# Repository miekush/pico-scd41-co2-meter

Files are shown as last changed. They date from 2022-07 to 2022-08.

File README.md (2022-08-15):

# Raspberry Pi Pico CO2 Meter

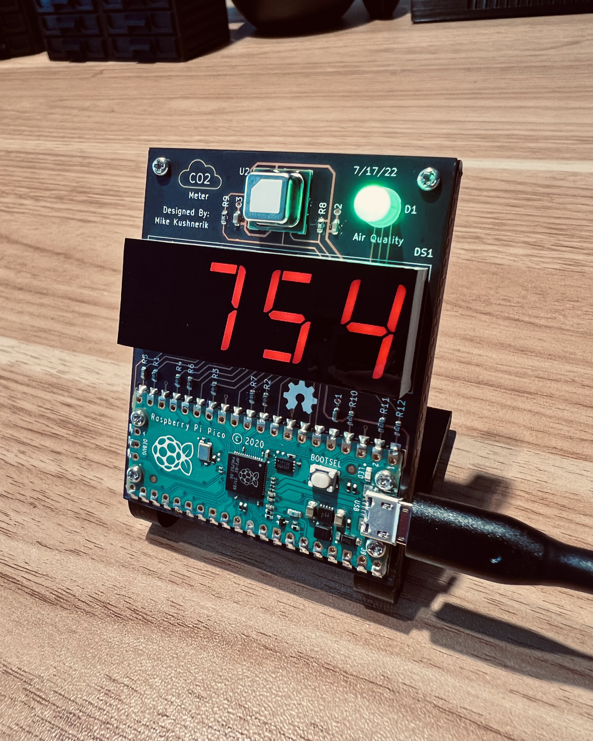
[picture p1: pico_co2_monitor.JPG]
Assembled Unit


# PCB
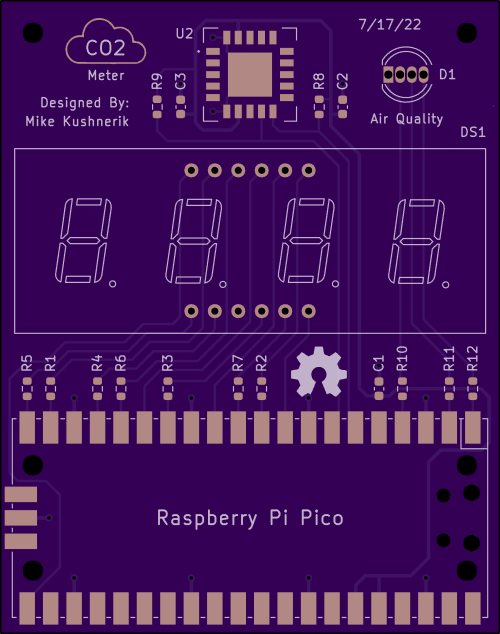
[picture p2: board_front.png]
Board Image


Designed by Mike Kushnerik (miekush) in KiCad V6

# License

MKE supports the open source hardware community by sharing hardware design files freely on GitHub!

Please support MKE by purchasing products on [Tindie](https://www.tindie.com/stores/mkengineering/)!

Designed by Mike Kushnerik (miekush)

Licensed under [Creative Commons Attribution-ShareAlike CC BY-SA 4.0](http://creativecommons.org/licenses/by-sa/4.0/)

All text above must be included in any redistribution!

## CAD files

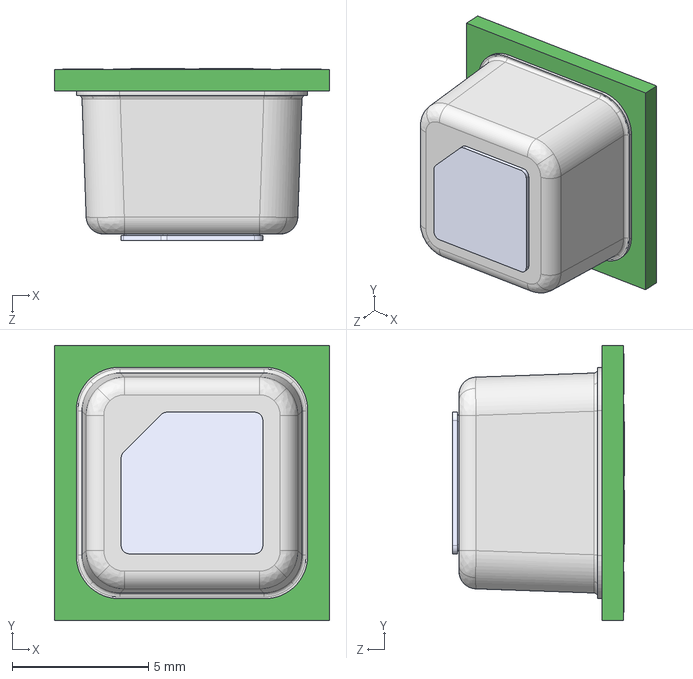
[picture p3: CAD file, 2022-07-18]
hardware/3D Models/Sensirion_CO2_Sensors_SCD4x_STEP_file.step
10.1 x 10.1 x 6.31 mm

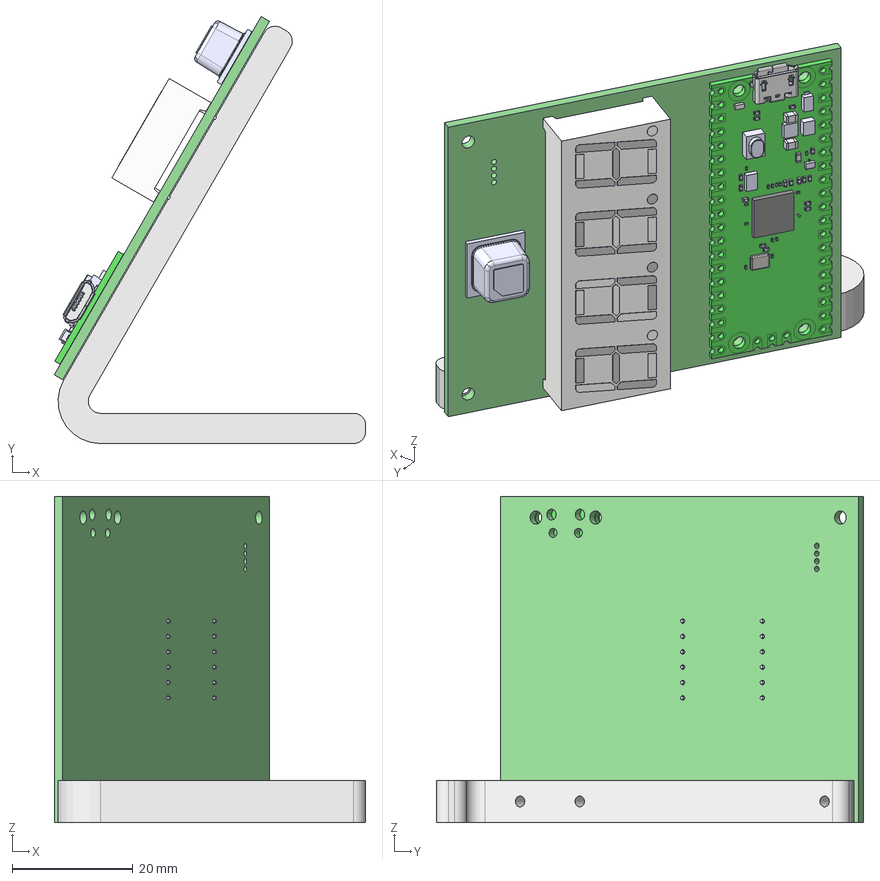
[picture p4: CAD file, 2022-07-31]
hardware/stand/pico_co2_meter_legs_v1.FCStd
51.6 x 70.7 x 54.0 mm
_autosave-pico_scd4x_co2_monitor_v1 PCB

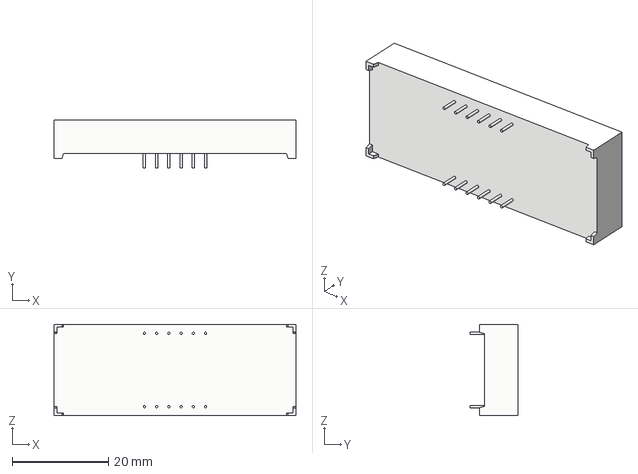
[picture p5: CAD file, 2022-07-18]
hardware/3D Models/7-Segment Display 4-Digit (5641).step
50.3 x 10.1 x 19.0 mm

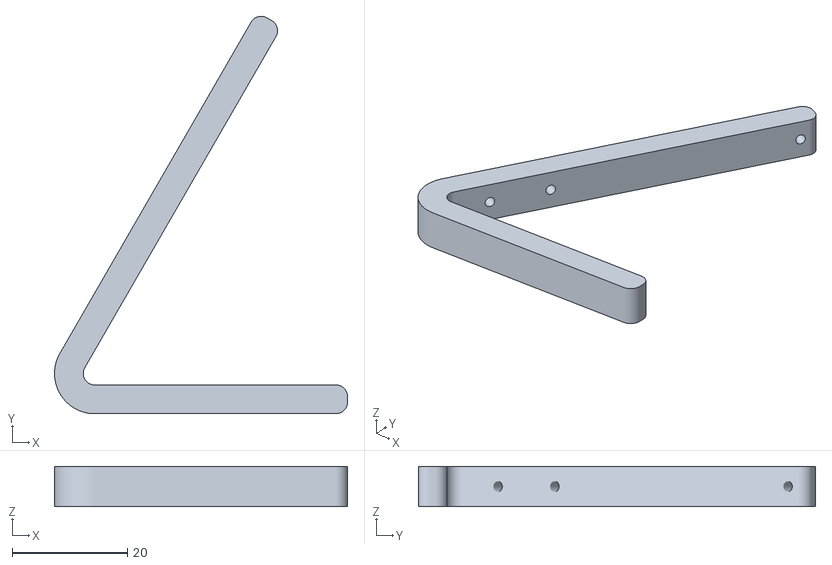
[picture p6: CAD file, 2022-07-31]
hardware/stand/pico_co2_meter_legs_v1-Body.stl
50.9 x 69.1 x 7.00

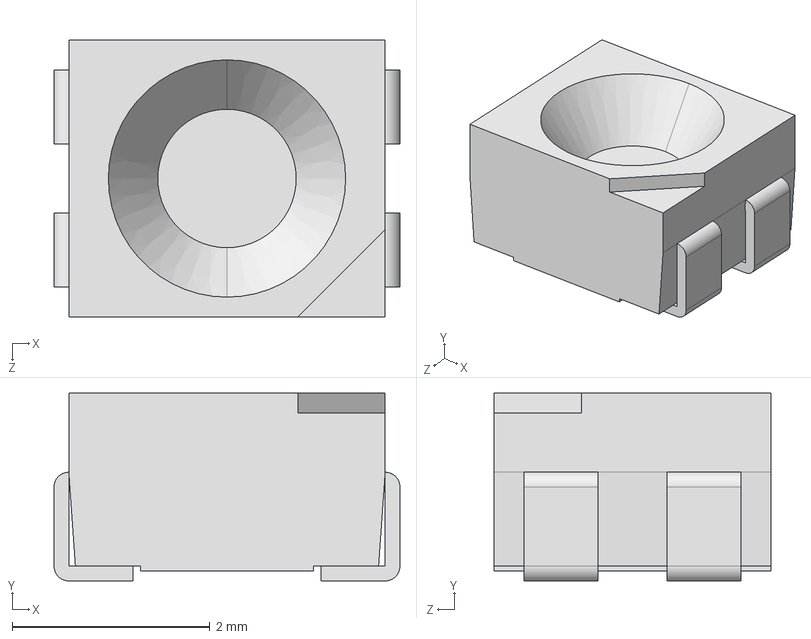
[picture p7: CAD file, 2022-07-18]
hardware/3D Models/XZxxxx45.step
3.50 x 1.90 x 2.80 mm

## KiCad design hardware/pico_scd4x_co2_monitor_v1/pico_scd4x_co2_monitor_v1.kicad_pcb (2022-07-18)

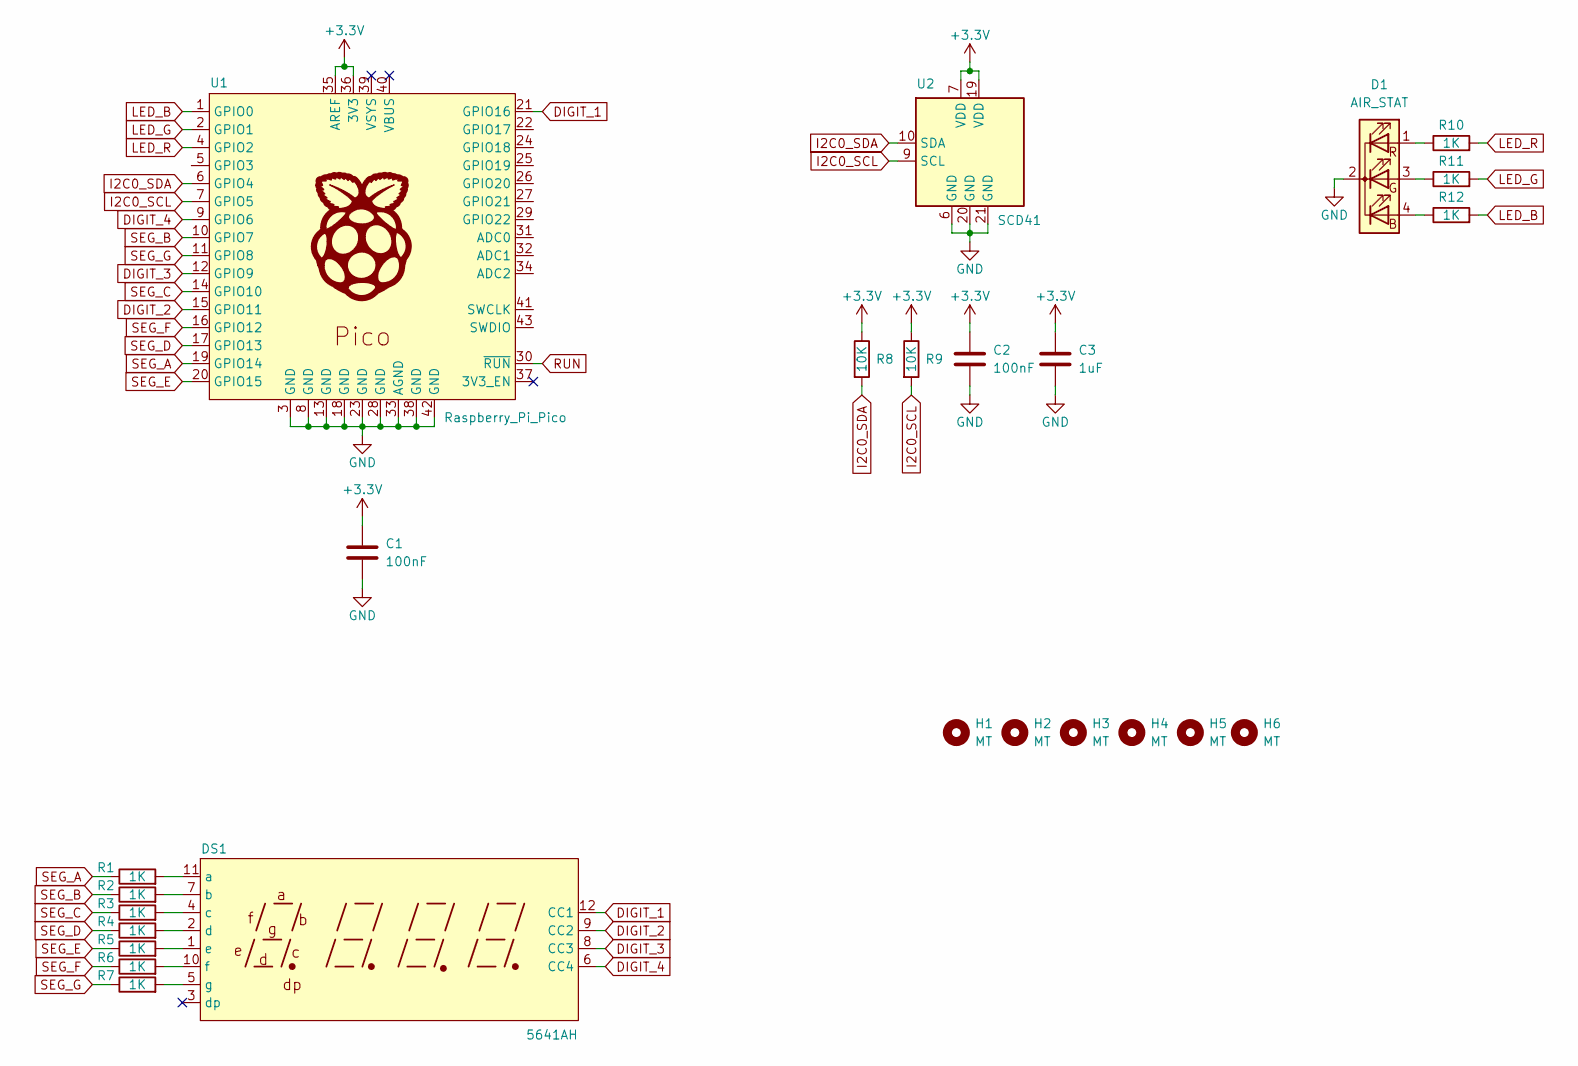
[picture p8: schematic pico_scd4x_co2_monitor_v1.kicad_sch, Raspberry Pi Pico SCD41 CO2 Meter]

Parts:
C1, C2: 100nF; C_0603_1608Metric
C3: 1uF; C_0603_1608Metric
D1: AIR_STAT; LED_D5.0mm-4_RGB
DS1: 5641AH
H1, H2, H3, H4, H5, H6: MT; MountingHole_2.2mm_M2
R1, R2, R3, R4, R5, R6, R7, R10, R11, R12: 1K; R_0603_1608Metric
R8, R9: 10K; R_0603_1608Metric
U1: Raspberry_Pi_Pico; RPi_Pico_SMD
U2: SCD41; SCD41DR2

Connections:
+3V3: C1.1, C2.1, C3.1, R8.1, R9.1, U1.35 (AREF), U1.36 (3V3), U2.7 (VDD), U2.19 (VDD)
DIGIT_1: DS1.12 (CC1), U1.21 (GPIO16)
DIGIT_2: DS1.9 (CC2), U1.15 (GPIO11)
DIGIT_3: DS1.8 (CC3), U1.12 (GPIO9)
DIGIT_4: DS1.6 (CC4), U1.9 (GPIO6)
GND: C1.2, C2.2, C3.2, D1.2 (K), U1.3 (GND), U1.8 (GND), U1.13 (GND), U1.18 (GND), U1.23 (GND), U1.28 (GND), U1.33 (AGND), U1.38 (GND), U1.42 (GND), U2.6 (GND), U2.20 (GND), U2.21 (GND)
I2C0_SCL: R9.2, U1.7 (GPIO5), U2.9 (SCL)
I2C0_SDA: R8.2, U1.6 (GPIO4), U2.10 (SDA)
LED_B: R12.2, U1.1 (GPIO0)
LED_G: R11.2, U1.2 (GPIO1)
LED_R: R10.2, U1.4 (GPIO2)
unnamed: D1.1 (RA), R10.1
unnamed: D1.3 (GA), R11.1
unnamed: D1.4 (BA), R12.1
unnamed: DS1.1 (e), R5.2
unnamed: DS1.2 (d), R4.2
unnamed: DS1.4 (c), R3.2
unnamed: DS1.5 (g), R7.2
unnamed: DS1.7 (b), R2.2
unnamed: DS1.10 (f), R6.2
unnamed: DS1.11 (a), R1.2
RUN: U1.30 (~RUN)
SEG_A: R1.1, U1.19 (GPIO14)
SEG_B: R2.1, U1.10 (GPIO7)
SEG_C: R3.1, U1.14 (GPIO10)
SEG_D: R4.1, U1.17 (GPIO13)
SEG_E: R5.1, U1.20 (GPIO15)
SEG_F: R6.1, U1.16 (GPIO12)
SEG_G: R7.1, U1.11 (GPIO8)

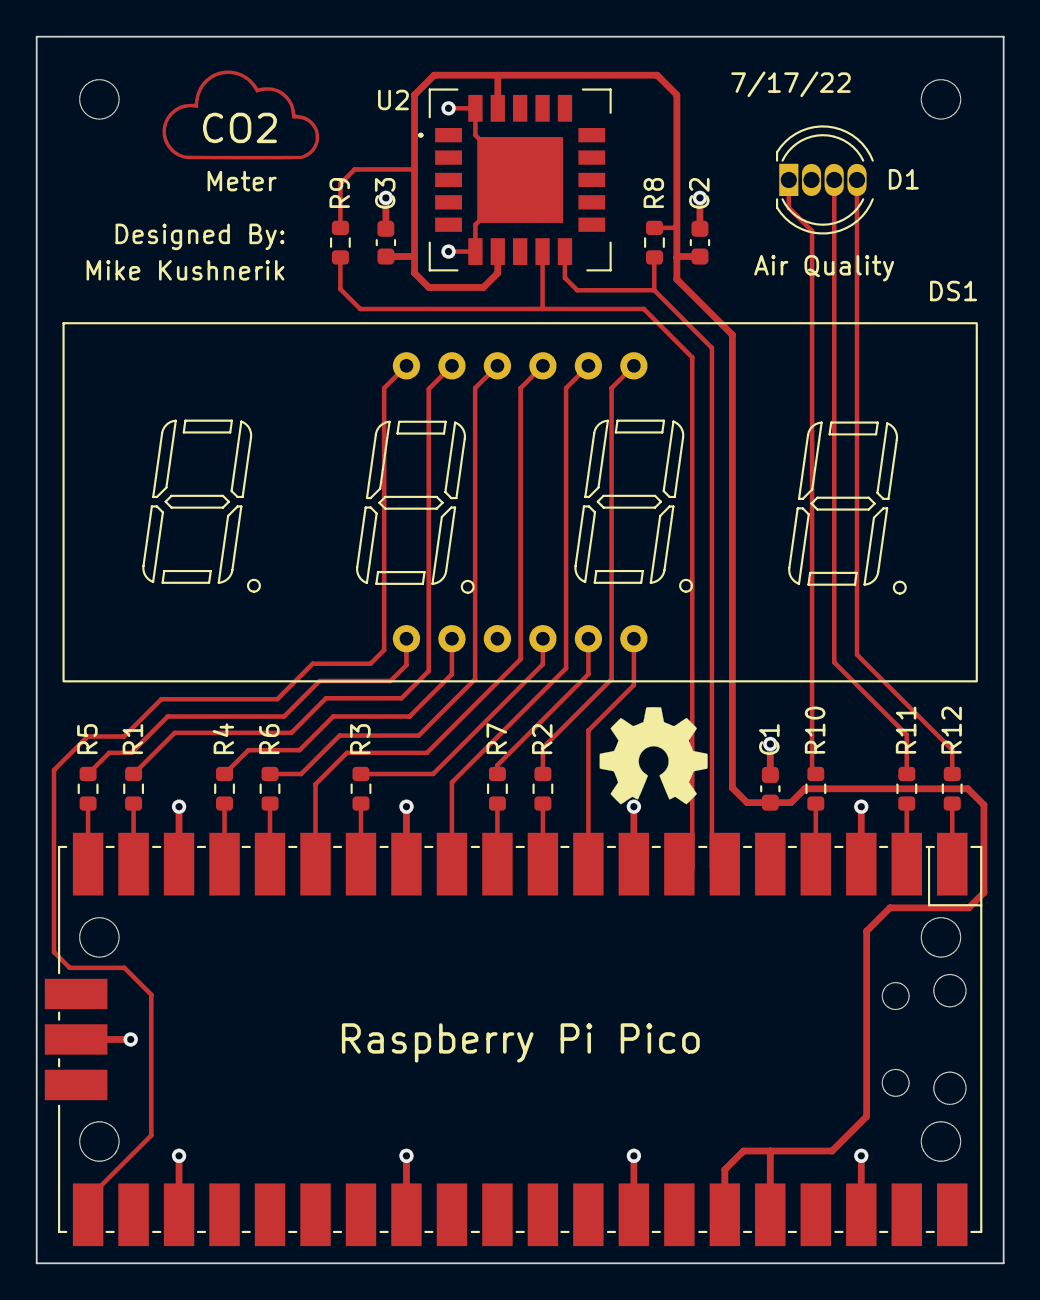
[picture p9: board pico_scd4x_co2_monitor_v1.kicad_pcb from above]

Board: 2 copper layers, 54.0 x 68.5 mm, 25 parts (0 on the bottom side), 28 nets.

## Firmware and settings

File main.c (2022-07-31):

//Raspberry Pi Pico SCD41 7 Segment
//Device: RP2040, SCD41, HS420561K-32 (CC 7-Segment Display)
//File: main.c
//Author: Mike Kushnerik
//Date: 7/15/2022

//I2C Bus Wiring (default):
//SDA = GP4
//SCL = GP5
//see sensirion_i2c_hal_init(void) in "sensirion_i2c_hal.c" to change from default

#include <stdio.h>
#include "scd4x_i2c.h"
#include "sensirion_common.h"
#include "sensirion_i2c_hal.h"
#include "pico/stdlib.h"
#include "hardware/gpio.h"

/* //7 segment wiring (adjust as needed):
#define a_pin       6
#define b_pin       7
#define c_pin       8
#define d_pin       9
#define e_pin       10
#define f_pin       11
#define g_pin       12
#define digit_1     13
#define digit_2     14
#define digit_3     15
#define digit_4     16 */

//7 segment wiring (adjust as needed):
#define a_pin       14
#define b_pin       7
#define c_pin       10
#define d_pin       13
#define e_pin       15
#define f_pin       12
#define g_pin       8
#define digit_1     16
#define digit_2     11
#define digit_3     9
#define digit_4     6

//rgb led pins:
#define led_r       2
#define led_g       1
#define led_b       0

//create mask for segment pins
const uint32_t segment_mask =   (1 << a_pin) |
                                (1 << b_pin) |
                                (1 << c_pin) |
                                (1 << d_pin) |
                                (1 << e_pin) |
                                (1 << f_pin) |
                                (1 << g_pin);

//create mask for digit pins
const uint32_t digit_mask =     (1 << digit_1) |
                                (1 << digit_2) |
                                (1 << digit_3) |
                                (1 << digit_4);

const uint32_t rgb_mask =       (1 << led_r) |
                                (1 << led_g) |
                                (1 << led_b);

//LUT for segment pins
//i.e. segment_pins[5] will display the value 5 on the display digit
const uint32_t segment_pins[10] =
{
    //0
    ((1<<a_pin) | (1<<b_pin) | (1<<c_pin) | (1<<d_pin) | (1<<e_pin) | (1<<f_pin)),
    //1
    ((1<<b_pin) | (1<<c_pin)),
    //2
    ((1<<a_pin) | (1<<b_pin) | (1<<d_pin) | (1<<e_pin) | (1<<g_pin)),
    //3
    ((1<<a_pin) | (1<<b_pin) | (1<<c_pin) | (1<<d_pin) | (1<<g_pin)),
    //4
    ((1<<b_pin) | (1<<c_pin) | (1<<f_pin) | (1<<g_pin)),
    //5
    ((1<<a_pin) | (1<<c_pin) | (1<<d_pin) | (1<<f_pin) | (1<<g_pin)),
    //6
    ((1<<a_pin) | (1<<c_pin) | (1<<d_pin) | (1<<e_pin) | (1<<f_pin) | (1<<g_pin)),
    //7
    ((1<<a_pin) | (1<<b_pin) | (1<<c_pin)),
    //8
    ((1<<a_pin) | (1<<b_pin) | (1<<c_pin) | (1<<d_pin) | (1<<e_pin) | (1<<f_pin) | (1<<g_pin)),
    //9
    ((1<<a_pin) | (1<<b_pin) | (1<<c_pin) | (1<<d_pin) | (1<<f_pin) | (1<<g_pin))
};

//LUT for digit pins
//i.e. digit_pins[0] is the most significant digit of the display
uint32_t digit_pins[4] =
{
    digit_1,
    digit_2,
    digit_3,
    digit_4
};

uint16_t co2 = 9999;
int32_t temperature = 0;
int32_t humidity = 0;
bool timerFlag = false;

//function prototypes
void init_display(void);
void update_display(uint16_t value);
void init_rgb(void);
void update_rgb(uint16_t value);

bool timer_cb(struct repeating_timer *t);

int main() 
{
    stdio_init_all();
    init_display();
    init_rgb();    

    sensirion_i2c_hal_init();

    scd4x_wake_up();
    scd4x_stop_periodic_measurement();
    scd4x_reinit();

    scd4x_start_periodic_measurement();

    //timer to poll scd41 every 5s
    struct repeating_timer timer;
    add_repeating_timer_ms(5000, timer_cb, NULL, &timer);

    while(1)
    {
        update_display(co2);
        update_rgb(co2);

        if(timerFlag)
        {
            //read scd41
            int16_t error = scd4x_read_measurement(&co2, &temperature, &humidity);
            //clear flag
            timerFlag = false;
        }
    }

    return 0;
}

//function to init the 7 segment display
void init_display(void)
{
    //init 7 segment output pins
    gpio_init_mask(segment_mask | digit_mask);
    //set pins as output
    gpio_set_dir_out_masked(segment_mask | digit_mask);
}

//function to init the rgb led
void init_rgb(void)
{
    //init the rgb output pins
    gpio_init_mask(rgb_mask);
    //set pins as output
    gpio_set_dir_out_masked(rgb_mask);
}

//function to update the value of the 7 segment display
void update_display(uint16_t value)
{
    //turn all digits off
    gpio_put_masked(digit_mask, digit_mask);
    //turn all segments off
    gpio_clr_mask(segment_mask);

    int i = 0;
    do
    {
        //turn all digits off
        gpio_put_masked(digit_mask, digit_mask);
        //select digit
        gpio_put(digit_pins[3-i], 0);
        //write digit value
        gpio_put_masked(segment_mask, segment_pins[value % 10]);
        //2000us seems to work well :p
        sleep_us(2000);
        i++;
    } while (value /= 10);
}

//function to update the air quality RGB led
void update_rgb(uint16_t value)
{
    //good air quality
    if(value < 800)
    {
        gpio_put(led_r, 0);
        gpio_put(led_g, 1);
        gpio_put(led_b, 0);
    }
    //average air quality
    else if (value >= 800 && value < 1000)
    {
        gpio_put(led_r, 1);
        gpio_put(led_g, 1);
        gpio_put(led_b, 0);
    }
    //bad air quality
    else
    {
        gpio_put(led_r, 1);
        gpio_put(led_g, 0);
        gpio_put(led_b, 0);        
    }
}

//timer interrupt callback to poll scd41
bool timer_cb(struct repeating_timer *t)
{
    //set flag
    timerFlag = true;
    return true;
}

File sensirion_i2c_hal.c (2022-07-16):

/*
 * Copyright (c) 2018, Sensirion AG
 * All rights reserved.
 *
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
 * * Neither the name of Sensirion AG nor the names of its
 *   contributors may be used to endorse or promote products derived from
 *   this software without specific prior written permission.
 *
 * THIS SOFTWARE IS PROVIDED BY THE COPYRIGHT HOLDERS AND CONTRIBUTORS "AS IS"
 * AND ANY EXPRESS OR IMPLIED WARRANTIES, INCLUDING, BUT NOT LIMITED TO, THE
 * IMPLIED WARRANTIES OF MERCHANTABILITY AND FITNESS FOR A PARTICULAR PURPOSE
 * ARE DISCLAIMED. IN NO EVENT SHALL THE COPYRIGHT HOLDER OR CONTRIBUTORS BE
 * LIABLE FOR ANY DIRECT, INDIRECT, INCIDENTAL, SPECIAL, EXEMPLARY, OR
 * CONSEQUENTIAL DAMAGES (INCLUDING, BUT NOT LIMITED TO, PROCUREMENT OF
 * SUBSTITUTE GOODS OR SERVICES; LOSS OF USE, DATA, OR PROFITS; OR BUSINESS
 * INTERRUPTION) HOWEVER CAUSED AND ON ANY THEORY OF LIABILITY, WHETHER IN
 * CONTRACT, STRICT LIABILITY, OR TORT (INCLUDING NEGLIGENCE OR OTHERWISE)
 * ARISING IN ANY WAY OUT OF THE USE OF THIS SOFTWARE, EVEN IF ADVISED OF THE
 * POSSIBILITY OF SUCH DAMAGE.
 */

#include "sensirion_i2c_hal.h"
#include "sensirion_common.h"
#include "sensirion_config.h"

#include <stdio.h>
#include "pico/stdlib.h"
#include "pico/binary_info.h"
#include "hardware/i2c.h"

/*
 * INSTRUCTIONS
 * ============
 *
 * Implement all functions where they are marked as IMPLEMENT.
 * Follow the function specification in the comments.
 */

/**
 * Select the current i2c bus by index.
 * All following i2c operations will be directed at that bus.
 *
 * THE IMPLEMENTATION IS OPTIONAL ON SINGLE-BUS SETUPS (all sensors on the same
 * bus)
 *
 * @param bus_idx   Bus index to select
 * @returns         0 on success, an error code otherwise
 */
int16_t sensirion_i2c_hal_select_bus(uint8_t bus_idx) {
}

/**
 * Initialize all hard- and software components that are needed for the I2C
 * communication.
 */
void sensirion_i2c_hal_init(void) {
    i2c_init(i2c_default, 100 * 1000);
    gpio_set_function(PICO_DEFAULT_I2C_SDA_PIN, GPIO_FUNC_I2C);
    gpio_set_function(PICO_DEFAULT_I2C_SCL_PIN, GPIO_FUNC_I2C);
    gpio_pull_up(PICO_DEFAULT_I2C_SDA_PIN);
    gpio_pull_up(PICO_DEFAULT_I2C_SCL_PIN);
}

/**
 * Release all resources initialized by sensirion_i2c_hal_init().
 */
void sensirion_i2c_hal_free(void) {
    //not needed for pico
}

/**
 * Execute one read transaction on the I2C bus, reading a given number of bytes.
 * If the device does not acknowledge the read command, an error shall be
 * returned.
 *
 * @param address 7-bit I2C address to read from
 * @param data    pointer to the buffer where the data is to be stored
 * @param count   number of bytes to read from I2C and store in the buffer
 * @returns 0 on success, error code otherwise
 */
int8_t sensirion_i2c_hal_read(uint8_t address, uint8_t* data, uint16_t count) {
    i2c_read_blocking(i2c_default, address, data, count, false);
    return 0;
}

/**
 * Execute one write transaction on the I2C bus, sending a given number of
 * bytes. The bytes in the supplied buffer must be sent to the given address. If
 * the slave device does not acknowledge any of the bytes, an error shall be
 * returned.
 *
 * @param address 7-bit I2C address to write to
 * @param data    pointer to the buffer containing the data to write
 * @param count   number of bytes to read from the buffer and send over I2C
 * @returns 0 on success, error code otherwise
 */
int8_t sensirion_i2c_hal_write(uint8_t address, const uint8_t* data,
                               uint16_t count) {
    i2c_write_blocking(i2c_default, address, data, count, false);
    return 0;
}

/**
 * Sleep for a given number of microseconds. The function should delay the
 * execution for at least the given time, but may also sleep longer.
 *
 * Despite the unit, a <10 millisecond precision is sufficient.
 *
 * @param useconds the sleep time in microseconds
 */
void sensirion_i2c_hal_sleep_usec(uint32_t useconds) {
    sleep_us((uint64_t)useconds);
}

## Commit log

2022-07-18 Add pcb KiCad files
    [7-Segment Display 4-Digit (5641).step, Sensirion_CO2_Sensors_SCD4x_STEP_file.step, XZxxxx45.step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]
2022-07-18 Add board photo
2022-07-31 Add hardware design files
    [pico_co2_meter_legs_v1-Body.stl, pico_co2_meter_legs_v1.FCStd]
